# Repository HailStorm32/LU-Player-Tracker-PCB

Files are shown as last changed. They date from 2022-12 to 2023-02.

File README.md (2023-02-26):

Photo of board
# Description
This repository holds the Eagle CAD PCB files for the LU Player Tracker board. You can find the code repository [here](https://github.com/HailStorm32/LU-Player-Tracker-Code). 

This board shows the player count and locations in real time by lighting up the respective world RGB LED and seven segment display. The player location and count is sent via MQTT from a Darkflame Universe private server. 

> Darkflame Universe is a server emulator for the defunct LEGO Universe MMO. You can find more info about the project [here](https://github.com/DarkflameUniverse/DarkflameServer)

# BOM

BOM
*Spreadsheet also in the repo*

---

Credit to `FutronBob` for the map layout that inspired this project

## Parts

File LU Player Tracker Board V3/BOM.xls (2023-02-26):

LU PLAYER TRACKER
Mouser # | Mfr. # | Manufacturer | Customer # | Description | RoHS | Lifecycle | Order Qty. | Price (USD) | Ext.: (USD)
485-4492 | 4492 | Adafruit |  | Adafruit Accessories NeoPixel Addressable 1515 LEDs (1.5mm x 1.5mm) - 10 pack - SK6805-E-J | RoHS Compliant |  | 2 | $3.95 | $7.90
485-373 | 373 | Adafruit |  | Adafruit Accessories 2.1mm DC Barrel Jack Breadboard Friendly | RoHS Compliant |  | 1 | $0.95 | $0.95
356-ESP32S3WRM1N16R8 | ESP32-S3-WROOM-1-N16R8 | Espressif |  | Multiprotocol Modules SMD Module, ESP32-S3R8, 3.3V, 8 MB Octal PSRAM Die, 16 MB Quad SPI Flash, PCB Antenna | RoHS Compliant | New Product | 1 | $4.31 | $4.31
595-TXU0304PWR | TXU0304PWR | Texas Instruments |  | Translation - Voltage Levels Four channel unidirectional level shifter | RoHS Compliant | New Product | 1 | $0.87 | $0.87
963-MSAST105SB7104KF | MSAST105SB7104KFNB25 | Taiyo Yuden |  | Multilayer Ceramic Capacitors MLCC - SMD/SMT 0402 25VDC 0.1uF 10% X7R | RoHS Compliant | New Product | 5 | $0.10 | $0.50
667-ERJ-2GEJ471X | ERJ-2GEJ471X | Panasonic |  | Thick Film Resistors - SMD 0402 470ohms 5% AEC-Q200 | RoHS Compliant By Exemption |  | 5 | $0.10 | $0.50
863-ESD9L5.0ST5G | ESD9L5.0ST5G | onsemi |  | ESD Suppressors / TVS Diodes ESD PROT DIODE UNI | RoHS Compliant |  | 4 | $0.38 | $1.52
490-UJ2-MIBH-G-SMTTR | UJ2-MIBH-G-SMT-TR | CUI Devices |  | USB Connectors USB jack, 2.0, micro B type, 5 pin, horizontal, gold flash, SMT, TR | RoHS Compliant |  | 1 | $0.45 | $0.45
611-KMT221GHFLFS | KMT221GHFLFS | C&K Switches |  | Tactile Switches SPST-NO, Off-Mom,SMT Tact | RoHS Compliant |  | 1 | $0.80 | $0.80
81-GRM155C81E105ME1J | GRM155C81E105ME11J | Murata |  | Multilayer Ceramic Capacitors MLCC - SMD/SMT 1.0UF 25V 20% 0402 | RoHS Compliant |  | 4 | $0.10 | $0.40
603-AC0402FR-7W10KL | AC0402FR-7W10KL | YAGEO |  | Thick Film Resistors - SMD 10k Ohms 62.5mW 0402 1% AEC-Q200 | RoHS Compliant By Exemption |  | 4 | $0.10 | $0.40
611-KXT321LHS | KXT321LHS | C&K Switches |  | Tactile Switches 20mA 15VDC 160gf 0.6mm SPST NO SMT | RoHS Compliant |  | 4 | $0.29 | $1.16
584-ADP3339AKCZ3.3R7 | ADP3339AKCZ-3.3-R7 | Analog Devices Inc. |  | Linear Voltage Regulators 1.5A anyCAP LDO | RoHS Compliant |  | 1 | $5.51 | $5.51
595-74LVC1G19DBVRE4 | SN74LVC1G19DBVRE4 | Texas Instruments |  | Encoders, Decoders, Multiplexers & Demultiplexers 1 of 2 Decoder Demultiplexer | RoHS Compliant |  | 1 | $0.40 | $0.40
771-74AHC138D-T | 74AHC138D,118 | Nexperia |  | Encoders, Decoders, Multiplexers & Demultiplexers 74AHC138D/SOT109/SO16 | RoHS Compliant |  | 1 | $0.42 | $0.42
630-HDSM-291C | HDSM-291C | Broadcom Limited |  | LED Displays & Accessories Red 624nm 7.5mcd CA DD 7 Segment | RoHS Compliant |  | 1 | $5.81 | $5.81
603-RC0402FR-07100RP | RC0402FR-07100RP | YAGEO |  | Thick Film Resistors - SMD 100 Ohms 62.5 mW 0402 1% | RoHS Compliant |  | 5 | $0.10 | $0.50

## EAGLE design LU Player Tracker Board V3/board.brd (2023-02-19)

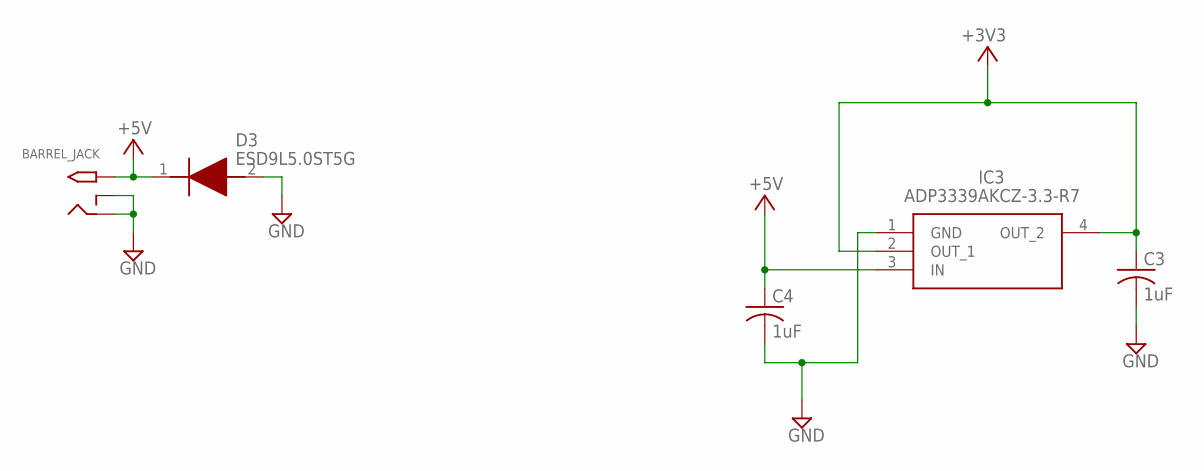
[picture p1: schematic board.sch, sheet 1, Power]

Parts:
BARREL_JACK: 2.1MMJACKTHM; PJ-102A
C3, C4: 1uF; C0402
D3: ESD9L5.0ST5G; SODFL1006X40N
IC3: ADP3339AKCZ-3.3-R7; SOT230P700X180-4N

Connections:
+3V3: C3.1, IC3.2 (OUT_1), IC3.4 (OUT_2); also elsewhere on the board
+5V: BARREL_JACK.TIP, C4.1, D3.1 (K), IC3.3 (IN); also elsewhere on the board
GND: BARREL_JACK.RING, BARREL_JACK.RING_SW, C3.2, C4.2, D3.2 (A), IC3.1 (GND); also elsewhere on the board

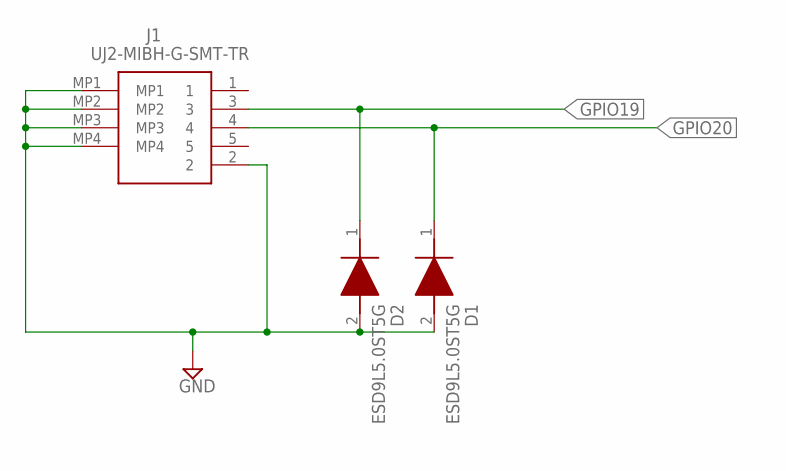
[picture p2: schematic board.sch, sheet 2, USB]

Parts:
D1, D2: ESD9L5.0ST5G; SODFL1006X40N
J1: UJ2-MIBH-G-SMT-TR; UJ2MIBHGSMTTR

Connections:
GND: D1.2 (A), D2.2 (A), J1.2, J1.MP1, J1.MP2, J1.MP3, J1.MP4; also elsewhere on the board
GPIO19: D2.1 (K), J1.3; also elsewhere on the board
GPIO20: D1.1 (K), J1.4; also elsewhere on the board

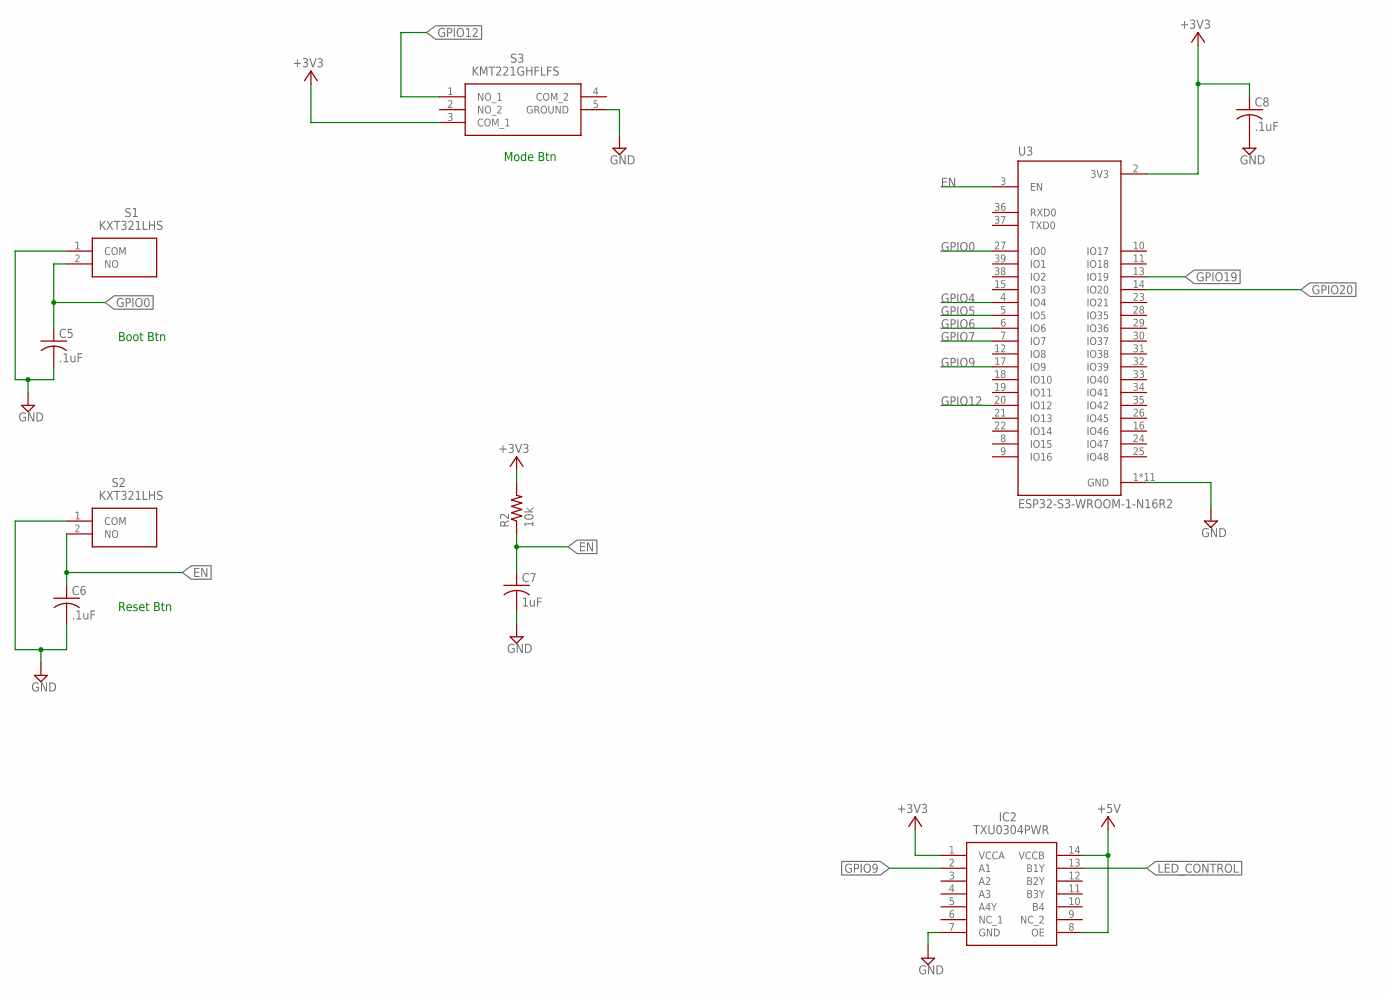
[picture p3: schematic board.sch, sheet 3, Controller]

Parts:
C5, C6, C8: .1uF; C0402
C7: 1uF; C0402
IC2: TXU0304PWR; SOP65P640X120-14N
R2: 10k; R0402
S1, S2: KXT321LHS
S3: KMT221GHFLFS
U3: ESP32-S3-WROOM-1-N16R2; XCVR_ESP32-S3-WROOM-1-N16R2

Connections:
+3V3: C8.1, IC2.1 (VCCA), R2.2, S3.3 (COM_1), U3.2 (3V3); also elsewhere on the board
+5V: IC2.8 (OE), IC2.14 (VCCB); also elsewhere on the board
EN: C6.1, C7.1, R2.1, S2.2 (NO), U3.3 (EN)
GND: C5.2, C6.2, C7.2, C8.2, IC2.7 (GND), S1.1 (COM), S2.1 (COM), S3.5 (GROUND), U3.1 (GND), U3.40 (GND), U3.41_1 (GND), U3.41_2 (GND), U3.41_3 (GND), U3.41_4 (GND), U3.41_5 (GND), U3.41_6 (GND), U3.41_7 (GND), U3.41_8 (GND), U3.41_9 (GND); also elsewhere on the board
GPIO0: C5.1, S1.2 (NO), U3.27 (IO0)
GPIO4: U3.4 (IO4); also elsewhere on the board
GPIO5: U3.5 (IO5); also elsewhere on the board
GPIO6: U3.6 (IO6); also elsewhere on the board
GPIO7: U3.7 (IO7); also elsewhere on the board
GPIO9: IC2.2 (A1), U3.17 (IO9)
GPIO12: S3.1 (NO_1), U3.20 (IO12)
GPIO19: U3.13 (IO19); also elsewhere on the board
GPIO20: U3.14 (IO20); also elsewhere on the board
LED_CONTROL: IC2.13 (B1Y); also elsewhere on the board

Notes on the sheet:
Reset Btn
Boot Btn
Mode Btn

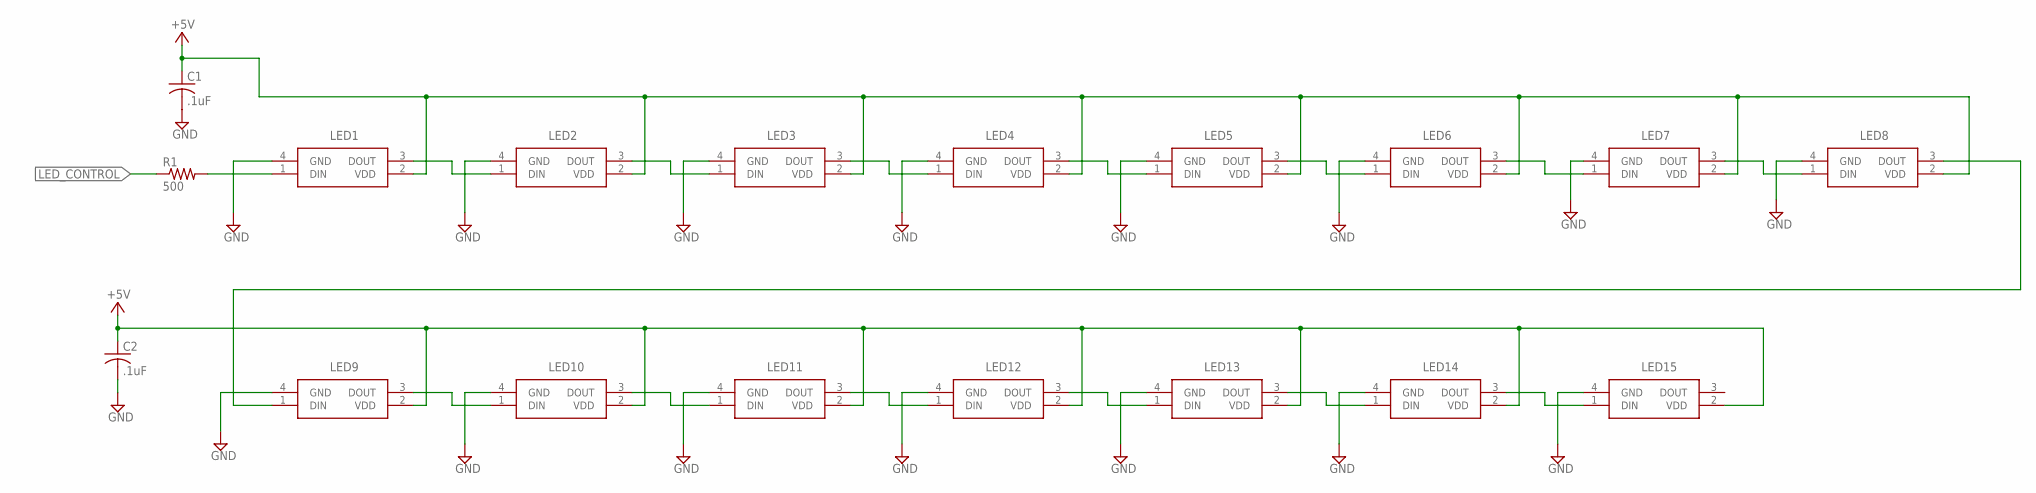
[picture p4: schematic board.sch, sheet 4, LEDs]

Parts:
C1, C2: .1uF; C0402
LED1, LED2, LED3, LED4, LED5, LED6, LED7, LED8, LED9, LED10, LED11, LED12, LED13, LED14, LED15: 4492__SK6805-EC_15_; 4492SK6805EC15
R1: 500; R0402

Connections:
+5V: C1.1, C2.1, LED1.2 (VDD), LED2.2 (VDD), LED3.2 (VDD), LED4.2 (VDD), LED5.2 (VDD), LED6.2 (VDD), LED7.2 (VDD), LED8.2 (VDD), LED9.2 (VDD), LED10.2 (VDD), LED11.2 (VDD), LED12.2 (VDD), LED13.2 (VDD), LED14.2 (VDD), LED15.2 (VDD); also elsewhere on the board
GND: C1.2, C2.2, LED1.4 (GND), LED2.4 (GND), LED3.4 (GND), LED4.4 (GND), LED5.4 (GND), LED6.4 (GND), LED7.4 (GND), LED8.4 (GND), LED9.4 (GND), LED10.4 (GND), LED11.4 (GND), LED12.4 (GND), LED13.4 (GND), LED14.4 (GND), LED15.4 (GND); also elsewhere on the board
LED_CONTROL: R1.1; also elsewhere on the board
unnamed: LED1.3 (DOUT), LED2.1 (DIN)
unnamed: LED2.3 (DOUT), LED3.1 (DIN)
unnamed: LED3.3 (DOUT), LED4.1 (DIN)
unnamed: LED4.3 (DOUT), LED5.1 (DIN)
unnamed: LED5.3 (DOUT), LED6.1 (DIN)
unnamed: LED6.3 (DOUT), LED7.1 (DIN)
unnamed: LED7.3 (DOUT), LED8.1 (DIN)
unnamed: LED8.3 (DOUT), LED9.1 (DIN)
unnamed: LED9.3 (DOUT), LED10.1 (DIN)
unnamed: LED10.3 (DOUT), LED11.1 (DIN)
unnamed: LED11.3 (DOUT), LED12.1 (DIN)
unnamed: LED12.3 (DOUT), LED13.1 (DIN)
unnamed: LED13.3 (DOUT), LED14.1 (DIN)
unnamed: LED14.3 (DOUT), LED15.1 (DIN)
unnamed: LED1.1 (DIN), R1.2

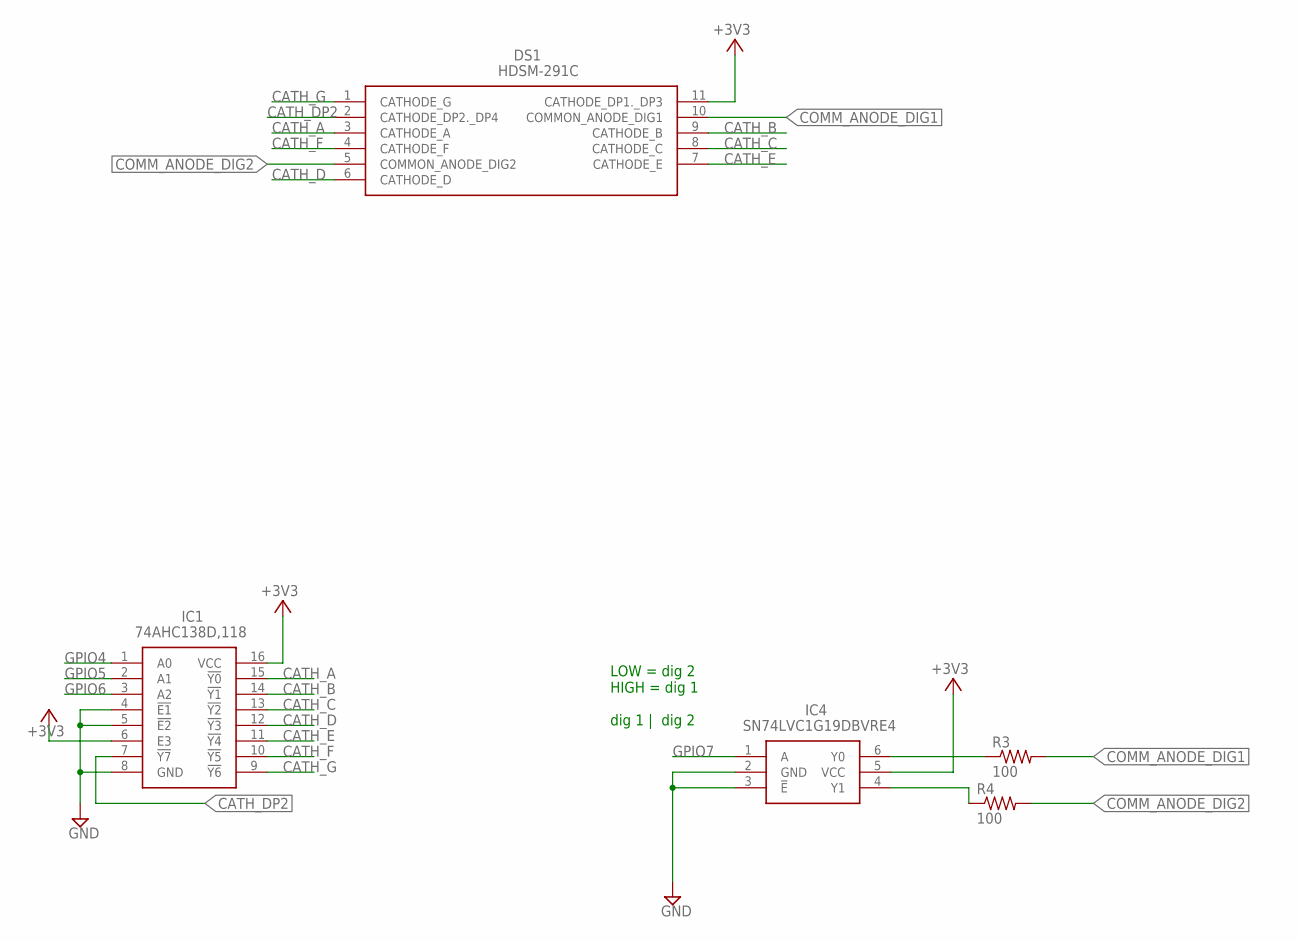
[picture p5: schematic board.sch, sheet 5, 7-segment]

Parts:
DS1: HDSM-291C; HDSM291C
IC1: 74AHC138D,118; SOIC127P600X175-16N
IC4: SN74LVC1G19DBVRE4; SOT95P280X145-6N
R3, R4: 100; R0402

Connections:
+3V3: DS1.11 (CATHODE_DP1._DP3), IC1.6 (E3), IC1.16 (VCC), IC4.5 (VCC); also elsewhere on the board
CATH_A: DS1.3 (CATHODE_A), IC1.15 (!Y0)
CATH_B: DS1.9 (CATHODE_B), IC1.14 (!Y1)
CATH_C: DS1.8 (CATHODE_C), IC1.13 (!Y2)
CATH_D: DS1.6 (CATHODE_D), IC1.12 (!Y3)
CATH_DP2: DS1.2 (CATHODE_DP2._DP4), IC1.7 (!Y7)
CATH_E: DS1.7 (CATHODE_E), IC1.11 (!Y4)
CATH_F: DS1.4 (CATHODE_F), IC1.10 (!Y5)
CATH_G: DS1.1 (CATHODE_G), IC1.9 (!Y6)
COMM_ANODE_DIG1: DS1.10 (COMMON_ANODE_DIG1), R3.2
COMM_ANODE_DIG2: DS1.5 (COMMON_ANODE_DIG2), R4.2
GND: IC1.4 (!E1), IC1.5 (!E2), IC1.8 (GND), IC4.2 (GND), IC4.3 (!E); also elsewhere on the board
GPIO4: IC1.1 (A0); also elsewhere on the board
GPIO5: IC1.2 (A1); also elsewhere on the board
GPIO6: IC1.3 (A2); also elsewhere on the board
GPIO7: IC4.1 (A); also elsewhere on the board
unnamed: IC4.6 (Y0), R3.1
unnamed: IC4.4 (Y1), R4.1

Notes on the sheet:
LOW = dig 2 HIGH = dig 1 dig 1 | dig 2

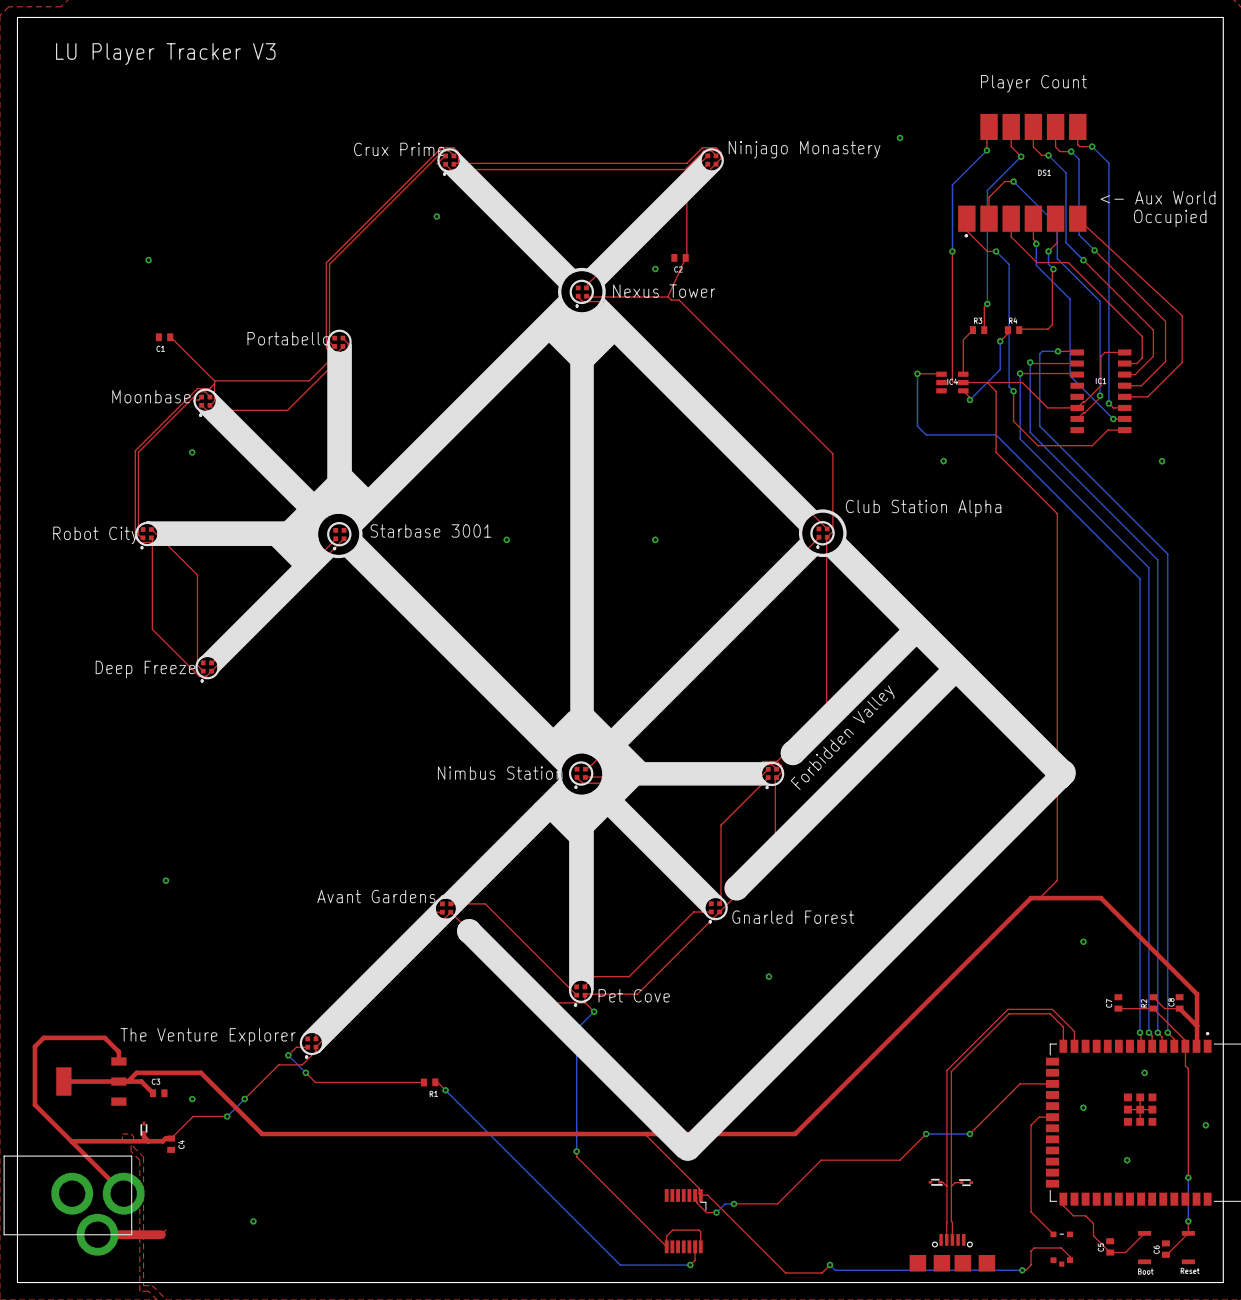
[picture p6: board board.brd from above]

Board: 2 copper layers, 138.0 x 144.8 mm, 41 parts (0 on the bottom side), 41 nets.

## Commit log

2022-12-07 Added all the main lines
    [board.brd]
2022-12-17 Updated to V2
    [board.brd, board.sch]
2023-01-22 v3 of board
    [board.brd, board.sch]
2023-02-11 resistor change
    [board.brd, board.sch]
2023-02-19 updated gitignore
    [board.brd]
2023-02-26 Added BOM
    [BOM.xls]
